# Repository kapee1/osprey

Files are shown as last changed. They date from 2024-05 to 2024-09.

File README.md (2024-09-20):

## Remix of the most beautiful ergonomic monosplit in my opinion


### Why did i do it? 
I really likes how does look original Osprey, but it is very difficult to assemble it yourself. This remix allows you to build it much easier and it still can be wireless! However, the assembly is not the easiest due to the size of the diodes.
### What changed? 
It uses SuperMini as controller. I used original PCB as template, so outline barely changed to fit a MSK swtich near USB-port. I have to slightly change case usb-hole and add a switch cutout. But original plate still fits. 
### Thanks
Huge thanks to the [ebastler](https://github.com/ebastler), author of the [original project](https://github.com/ebastler/osprey) for the inspiration and for the great work he did on the original project and [aroum](https://github.com/aroum) for his kind help and advices. 
### BOM
To build firmware, simply clone this repo: https://github.com/kapee1/osprey-remix-zmk-config

| Part |  Amount | |
| --- | --- | --- |
| Osprey-remix PCB |  1  |  1.2mm |
| Osprey Plate |  1  |  1.2mm |
| Osprey-remix Bottom case | 1  | |
| Osprey-remix Top case | 1  | |
| M2 x 8mm screws |  9 | |
| Threaded M2 inserts |  9 | |
| SuperMini or Nice!Nano |  1 | |
| Kailh Choc Hotswap sockets |  42 | |
| 1N4148WS SOD-323 Diodes |  42  | |
| MSK-12C01 Switch |  1 | |
| 502030 Battery |  1 | |
| Round 8mm feets |  7 | |

## Photos 





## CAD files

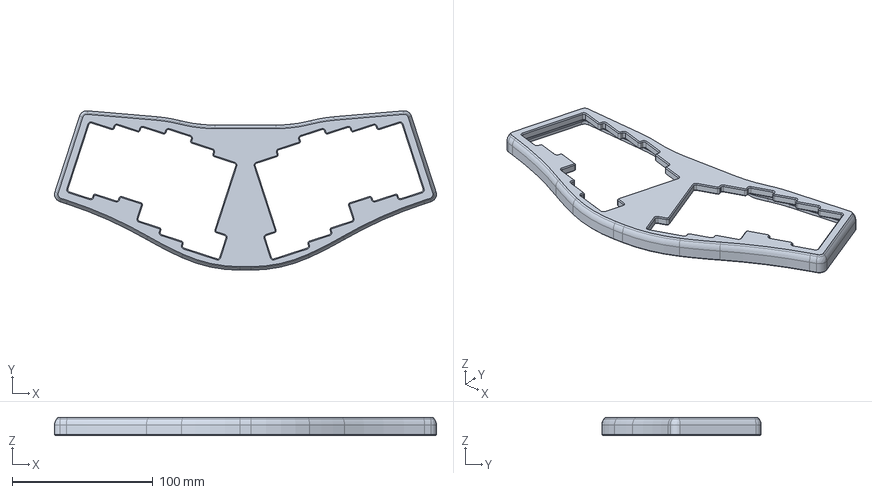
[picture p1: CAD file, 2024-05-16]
osprey_enclosure/osprey_enclosure_top.step
271.9 x 113.5 x 13.1 mm

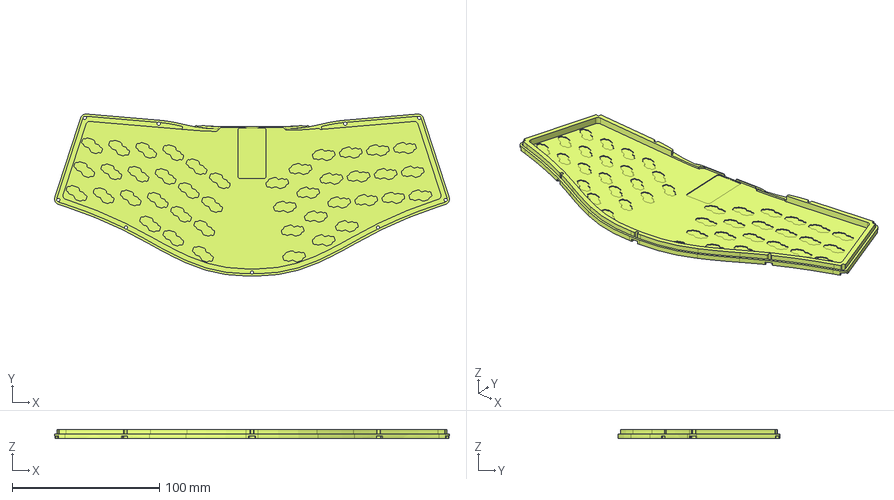
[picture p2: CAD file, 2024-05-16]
osprey_enclosure/osprey_enclosure_bot.step
268.6 x 110.2 x 6.40 mm

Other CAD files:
osprey_enclosure/osprey_enclosure.f3d

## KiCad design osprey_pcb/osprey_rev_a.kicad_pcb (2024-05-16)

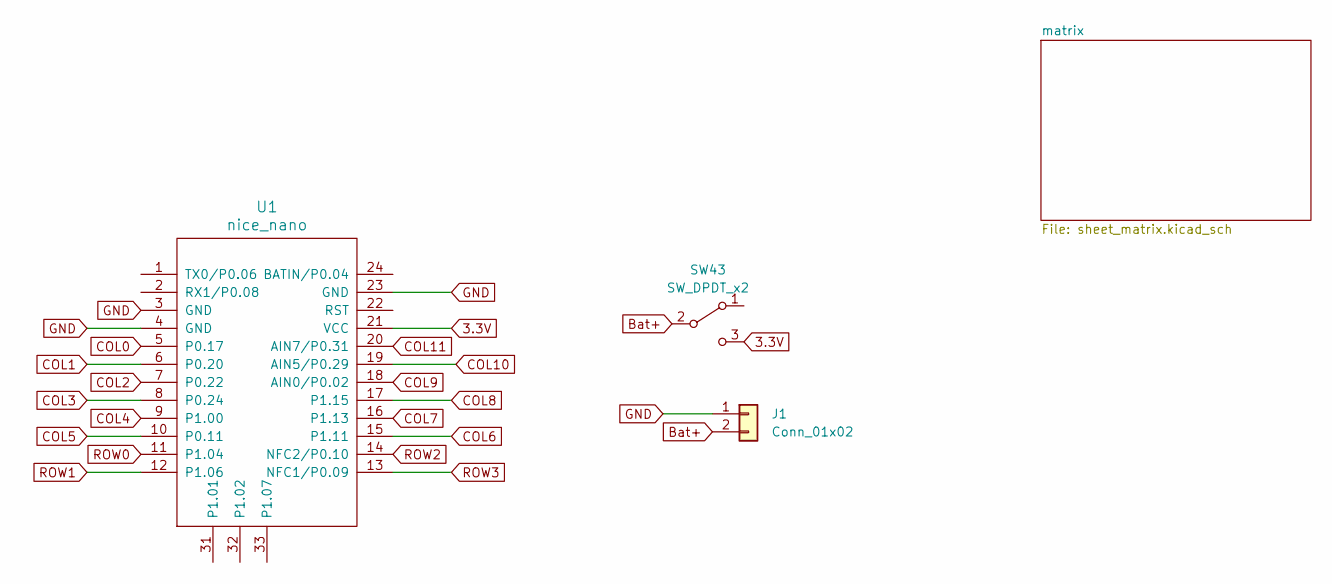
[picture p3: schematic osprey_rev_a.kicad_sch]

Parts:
J1: Conn_01x02; JST_ACH_BM02B-ACHSS-GAN-ETF_1x02-1MP_P1.20mm_Vertical
SW43: SW_DPDT_x2; MSK12C02
U1: nice_nano; NiceNano

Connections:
3.3V: SW43.3 (C), U1.21 (VCC), U1.26
Bat+: J1.2, SW43.2 (B); also elsewhere on the board
COL0: U1.5 (P0.17); also elsewhere on the board
COL1: U1.6 (P0.20); also elsewhere on the board
COL2: U1.7 (P0.22); also elsewhere on the board
COL3: U1.8 (P0.24); also elsewhere on the board
COL4: U1.9 (P1.00); also elsewhere on the board
COL5: U1.10 (P0.11); also elsewhere on the board
COL6: U1.15 (P1.11); also elsewhere on the board
COL7: U1.16 (P1.13); also elsewhere on the board
COL8: U1.17 (P1.15); also elsewhere on the board
COL9: U1.18 (AIN0/P0.02); also elsewhere on the board
COL10: U1.19 (AIN5/P0.29); also elsewhere on the board
COL11: U1.20 (AIN7/P0.31); also elsewhere on the board
GND: J1.1, U1.3 (GND), U1.4 (GND), U1.23 (GND), U1.25; also elsewhere on the board
ROW0: U1.11 (P1.04); also elsewhere on the board
ROW1: U1.12 (P1.06); also elsewhere on the board
ROW2: U1.14 (NFC2/P0.10); also elsewhere on the board
ROW3: U1.13 (NFC1/P0.09); also elsewhere on the board

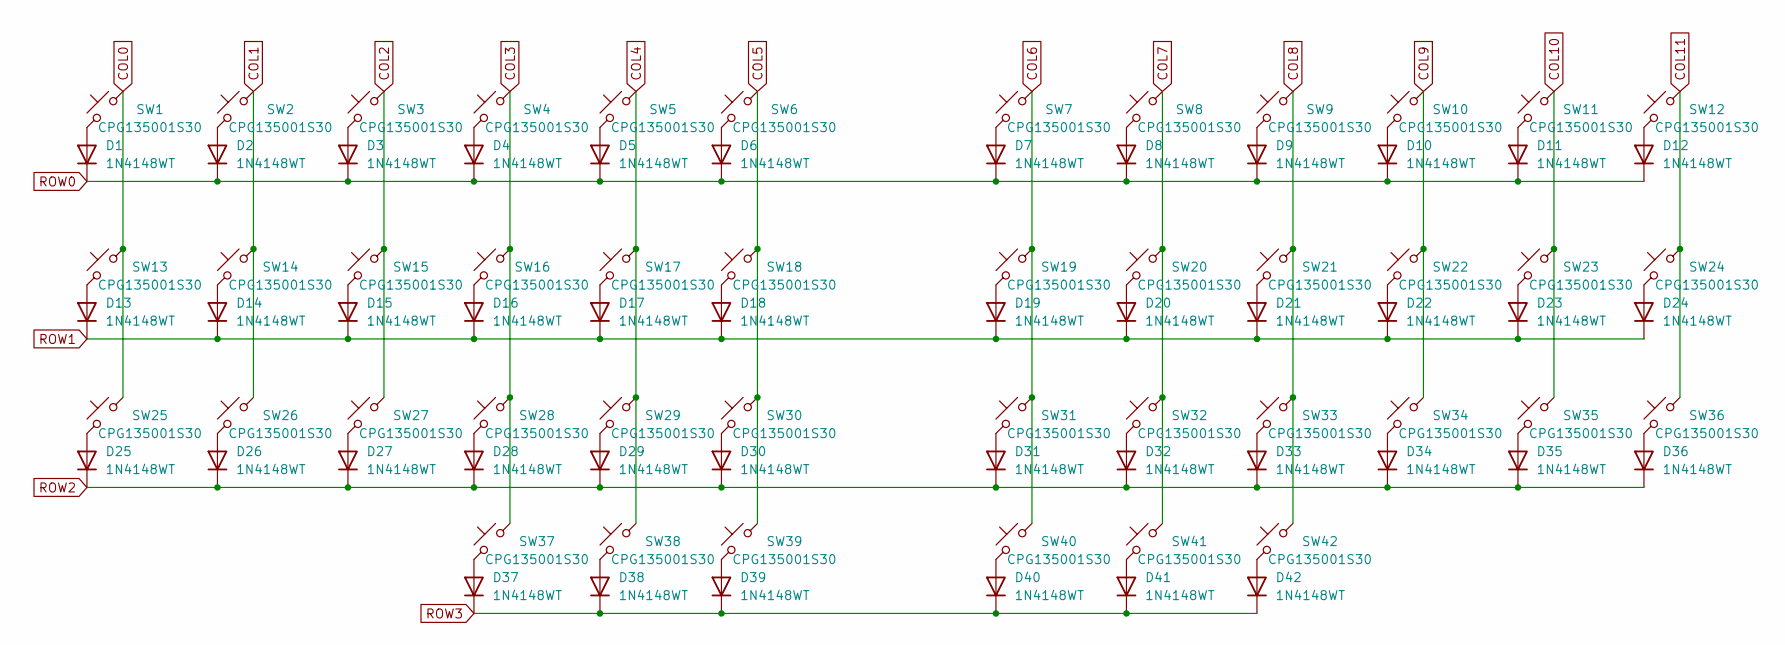
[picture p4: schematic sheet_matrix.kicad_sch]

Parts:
D1, D2, D3, D4, D5, D6, D7, D8, D9, D10, D11, D12, D13, D14, D15, D16, D17, D18, D19, D20, D21, D22, D23, D24, D25, D26, D27, D28, D29, D30, D31, D32, D33, D34, D35, D36, D37, D38, D39, D40, D41, D42: 1N4148WT; D_SOD-323_HandSoldering
SW1, SW2, SW3, SW4, SW5, SW6, SW7, SW8, SW9, SW10, SW11, SW12, SW13, SW14, SW15, SW16, SW17, SW18, SW19, SW20, SW21, SW22, SW23, SW24, SW25, SW26, SW27, SW28, SW29, SW30, SW31, SW32, SW33, SW34, SW35, SW36, SW37, SW38, SW41, SW42: CPG135001S30; SW_choc_HS_1u
SW39, SW40: CPG135001S30; SW_choc_HS_1.5u

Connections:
COL0: SW1.1, SW13.1, SW25.1; also elsewhere on the board
COL1: SW2.1, SW14.1, SW26.1; also elsewhere on the board
COL2: SW3.1, SW15.1, SW27.1; also elsewhere on the board
COL3: SW4.1, SW16.1, SW28.1, SW37.1; also elsewhere on the board
COL4: SW5.1, SW17.1, SW29.1, SW38.1; also elsewhere on the board
COL5: SW6.1, SW18.1, SW30.1, SW39.1; also elsewhere on the board
COL6: SW7.1, SW19.1, SW31.1, SW40.1; also elsewhere on the board
COL7: SW8.1, SW20.1, SW32.1, SW41.1; also elsewhere on the board
COL8: SW9.1, SW21.1, SW33.1, SW42.1; also elsewhere on the board
COL9: SW10.1, SW22.1, SW34.1; also elsewhere on the board
COL10: SW11.1, SW23.1, SW35.1; also elsewhere on the board
COL11: SW12.1, SW24.1, SW36.1; also elsewhere on the board
unnamed: D1.2 (A), SW1.2
unnamed: D2.2 (A), SW2.2
unnamed: D3.2 (A), SW3.2
unnamed: D4.2 (A), SW4.2
unnamed: D5.2 (A), SW5.2
unnamed: D6.2 (A), SW6.2
unnamed: D7.2 (A), SW7.2
unnamed: D8.2 (A), SW8.2
unnamed: D9.2 (A), SW9.2
unnamed: D10.2 (A), SW10.2
unnamed: D11.2 (A), SW11.2
unnamed: D12.2 (A), SW12.2
unnamed: D13.2 (A), SW13.2
unnamed: D14.2 (A), SW14.2
unnamed: D15.2 (A), SW15.2
unnamed: D16.2 (A), SW16.2
unnamed: D17.2 (A), SW17.2
unnamed: D18.2 (A), SW18.2
unnamed: D19.2 (A), SW19.2
unnamed: D20.2 (A), SW20.2
unnamed: D21.2 (A), SW21.2
unnamed: D22.2 (A), SW22.2
unnamed: D23.2 (A), SW23.2
unnamed: D24.2 (A), SW24.2
unnamed: D25.2 (A), SW25.2
unnamed: D26.2 (A), SW26.2
unnamed: D27.2 (A), SW27.2
unnamed: D28.2 (A), SW28.2
unnamed: D29.2 (A), SW29.2
unnamed: D30.2 (A), SW30.2
unnamed: D31.2 (A), SW31.2
unnamed: D32.2 (A), SW32.2
unnamed: D33.2 (A), SW33.2
unnamed: D34.2 (A), SW34.2
unnamed: D35.2 (A), SW35.2
unnamed: D36.2 (A), SW36.2
unnamed: D37.2 (A), SW37.2
unnamed: D38.2 (A), SW38.2
unnamed: D39.2 (A), SW39.2
unnamed: D40.2 (A), SW40.2
unnamed: D41.2 (A), SW41.2
unnamed: D42.2 (A), SW42.2
ROW0: D1.1 (K), D2.1 (K), D3.1 (K), D4.1 (K), D5.1 (K), D6.1 (K), D7.1 (K), D8.1 (K), D9.1 (K), D10.1 (K), D11.1 (K), D12.1 (K); also elsewhere on the board
ROW1: D13.1 (K), D14.1 (K), D15.1 (K), D16.1 (K), D17.1 (K), D18.1 (K), D19.1 (K), D20.1 (K), D21.1 (K), D22.1 (K), D23.1 (K), D24.1 (K); also elsewhere on the board
ROW2: D25.1 (K), D26.1 (K), D27.1 (K), D28.1 (K), D29.1 (K), D30.1 (K), D31.1 (K), D32.1 (K), D33.1 (K), D34.1 (K), D35.1 (K), D36.1 (K); also elsewhere on the board
ROW3: D37.1 (K), D38.1 (K), D39.1 (K), D40.1 (K), D41.1 (K), D42.1 (K); also elsewhere on the board

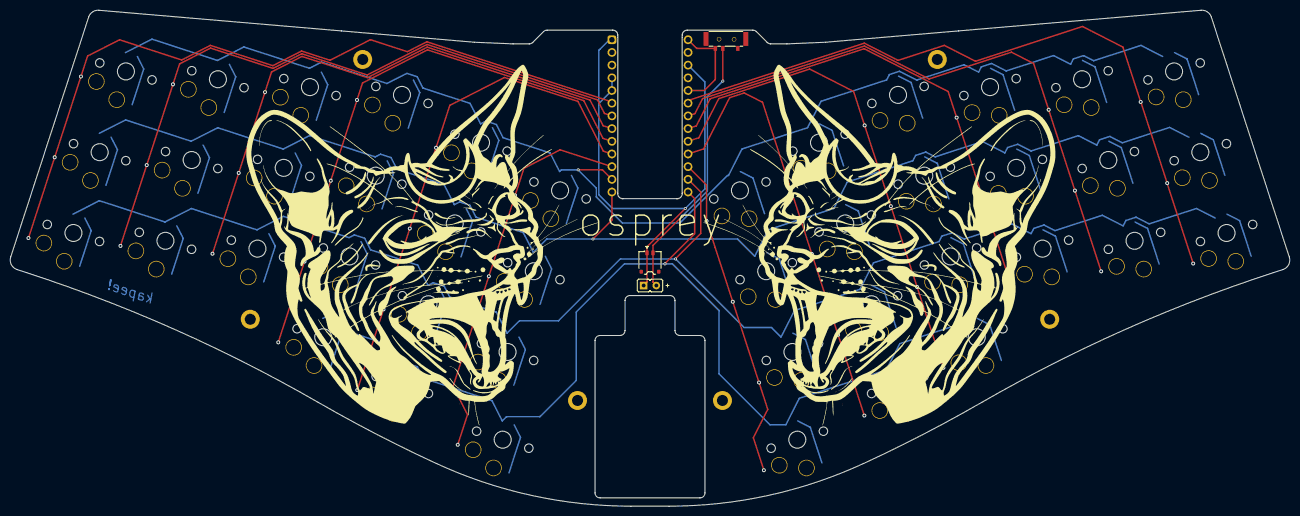
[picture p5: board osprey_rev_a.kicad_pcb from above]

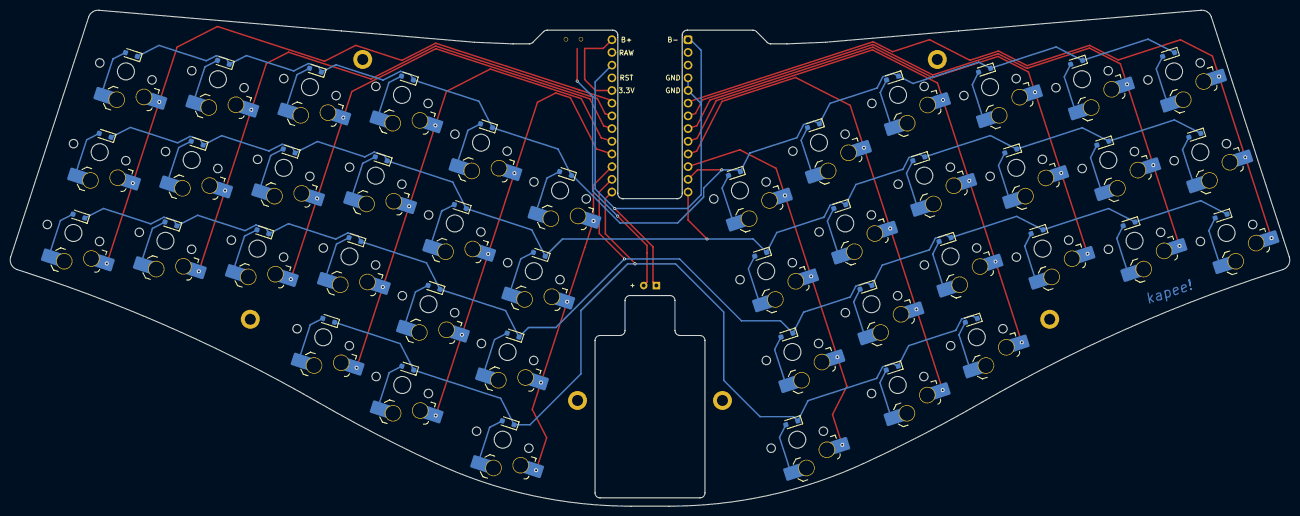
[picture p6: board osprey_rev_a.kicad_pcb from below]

Board: 2 copper layers, 256.1 x 99.3 mm, 94 parts (88 on the bottom side), 61 nets.

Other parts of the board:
H1, H2, H3, H4, H5, H6: M2; MountingHole_2.2mm_M2_DIN965_Pad
J3: Conn_01x02_Male; PinHeader_1x2_P2.54mm_Vertical

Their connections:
Bat+: J3.2; also elsewhere on the board
GND: J3.1; also elsewhere on the board
